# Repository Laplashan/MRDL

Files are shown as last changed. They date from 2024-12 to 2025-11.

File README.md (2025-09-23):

<header>

<!--
  <<< Author notes: Course header >>>
  Include a 1280×640 image, course title in sentence case, and a concise description in emphasis.
  In your repository settings: enable template repository, add your 1280×640 social image, auto delete head branches.
  Add your open source license, GitHub uses MIT license.
-->

# MRDL V0.2

_Tools, documentation and background of our datalogger._

</header>

<!--
  <<< Author notes: Step 1 >>>
  Choose 3-5 steps for your course.
  The first step is always the hardest, so pick something easy!
  Link to docs.github.com for further explanations.
  Encourage users to open new tabs for steps!
-->

## Introduction

_Welcome everyone_

MRDL was born from the necessity of getting a better undarstanding of the dynamics of our car. The motivation behind this repository is an exploration into the world of DIY electronics, the end goal being to create a functional prototype that can be permanently mounted on our MR23C.
The data logging system consists of 3 key aspects:

Firmware, this program is flashed onto the micro-controller so as to control its general operation and communicate with the server software.

Server software, this program exposes various API endpoints which handle hardware registration, configuration and telemetry.

Client software, this program is the source code for a web based interface for hardware reporting and configuration. (Currently using Blynk)

## Objective and needs (Constantly updating)

To get a better understanding of our car we need to be able to read data from various sectors, wich can include temperature, speed, position, acceleration, impacts, etc.
In this section, we´ll add a quick list mencioning the key spots to get data from, and what sensor/implement can be used to get that data as well as if its covered or not.

1. Speed | GPS sensor | Status: Completed. | Mounted anywhere on the car.
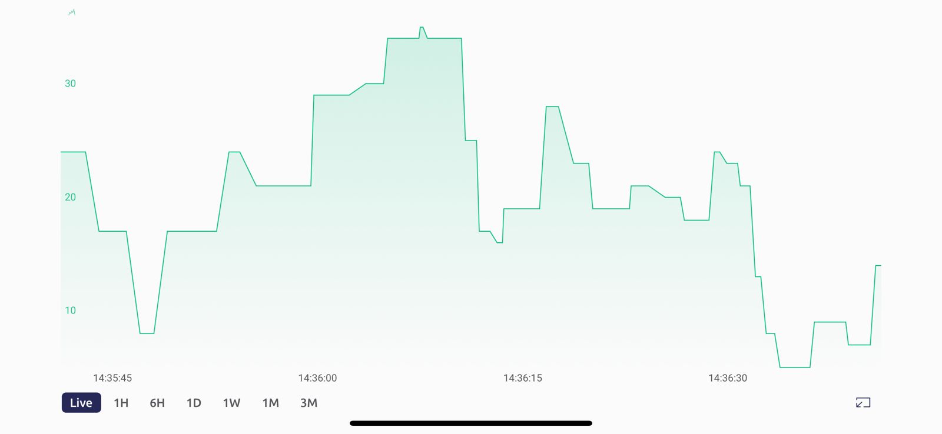
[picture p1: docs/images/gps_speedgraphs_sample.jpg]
speed
     
2. Position tracking | GPS sensor | Status: Partially completed (Issues w/ Blynk cloud) | Mounted anywhere on the car.
3. Engine RPM | Hall Effect | Status: 90% completed | Running in an Arduino board and sent thorugh Serial
4. Suspension shock dynamics | Unknown | Status: 0% | -
5. Reductor temp. | Thermocouple XS 168 or similar | Status: Partially completed, prog. completed, sensor unmounted | Bolted directly on the reductor.

Get help: [Post in our discussion board](https://github.com/orgs/skills/discussions/categories/introduction-to-github) &bull; [Review the GitHub status page](https://www.githubstatus.com/)

&copy; 2024 GitHub &bull; [Code of Conduct](https://www.contributor-covenant.org/version/2/1/code_of_conduct/code_of_conduct.md) &bull; [MIT License](https://gh.io/mit)

</footer>

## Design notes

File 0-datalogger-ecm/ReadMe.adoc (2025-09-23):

:Author: ernestrks
:Email:
:Date: 17/08/2025
:Revision: version#
:License: Public Domain

= Project: {Project}

Describe your project

== Step 1: Installation
Please describe the steps to install this project.

For example:

1. Open this file
2. Edit as you like
3. Release to the World!

== Step 2: Assemble the circuit

Assemble the circuit following the diagram layout.png attached to the sketch

== Step 3: Load the code

Upload the code contained in this sketch on to your board

=== Folder structure

....
 sketch123                => Arduino sketch folder
  ├── sketch123.ino       => main Arduino file
  ├── schematics.png      => (optional) an image of the required schematics
  ├── layout.png          => (optional) an image of the layout
  └── ReadMe.adoc         => this file
....

=== License
This project is released under a {License} License.

=== Contributing
To contribute to this project please contact: 

=== BOM
Add the bill of the materials you need for this project.

|===
| ID | Part name      | Part number | Quantity
| R1 | 10k Resistor   | 1234-abcd   | 10       
| L1 | Red LED        | 2345-asdf   | 5        
| A1 | Arduino Zero   | ABX00066    | 1        
|===

=== Help
This document is written in the _AsciiDoc_ format, a markup language to describe documents. 
If you need help you can search the http://www.methods.co.nz/asciidoc[AsciiDoc homepage]
or consult the http://powerman.name/doc/asciidoc[AsciiDoc cheatsheet]

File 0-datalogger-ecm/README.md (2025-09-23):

# Datalogger ECM
WEEMOS D1 Mini ESP3266
## Description
Captures and stores real-time data from other vehicle ECM and sensors for diagnostics and performance analysis.

## Folder Structure
- `src/` - Logging and data management code
- `tests/` - Test scripts for data integrity and performance
- `storage/` - Data formats and archival logic

## Dependencies
- ArduinoIoTCloud
- TinyGPSPlus

## Build Instructions
To build code for the ESP8266 using the Arduino IDE, follow these steps:

✅ 1. Install Arduino IDE
Download and install the latest version from arduino.cc.

✅ 2. Add ESP8266 Board Support
Open Arduino IDE.
Go to File > Preferences.
In the Additional Board Manager URLs, add:
http://arduino.esp8266.com/stable/package_esp8266com_index.json
Click OK.
✅ 3. Install ESP8266 Board Package
Go to Tools > Board > Boards Manager.
Search for ESP8266.
Click Install on the package by ESP8266 Community.
✅ 4. Select Your ESP8266 Board
Go to Tools > Board, and choose your specific board (e.g., NodeMCU 1.0, Wemos D1 Mini, etc.).

✅ 5. Connect Your Board
Plug in your ESP8266 via USB.
Select the correct Port under Tools > Port.
✅ 6. Write or Load Your Code

## Versioning
Current version: 0.0.0
Version history is tracked via Git tags: `datalogger-ecm-vX.Y.Z`

## Contact
Ernest
    github.com/Laplashan
    ernesto.ts06@gmail.com

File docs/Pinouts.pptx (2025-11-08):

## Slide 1

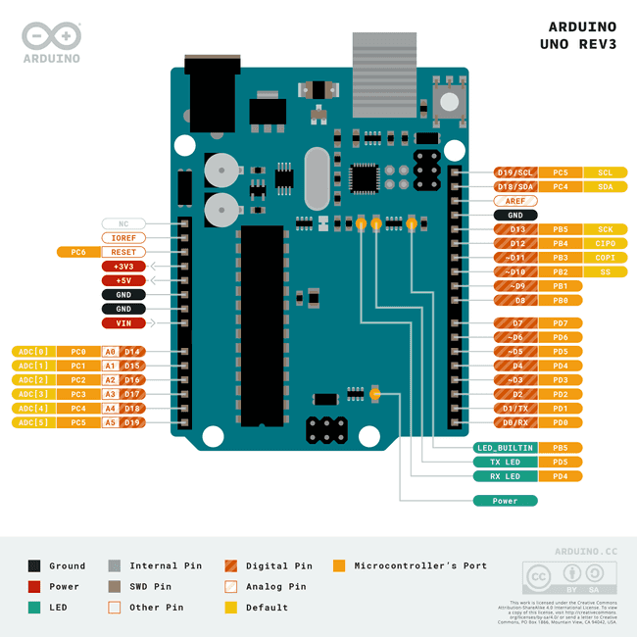
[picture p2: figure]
Arduino UNO Rev3 with Long Pins | Arduino Documentation
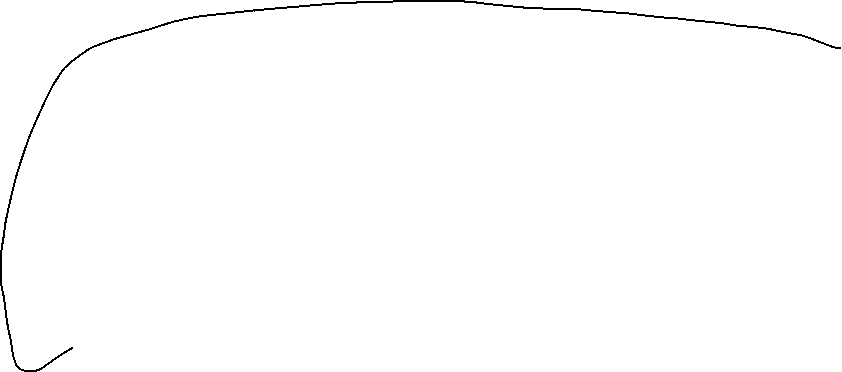
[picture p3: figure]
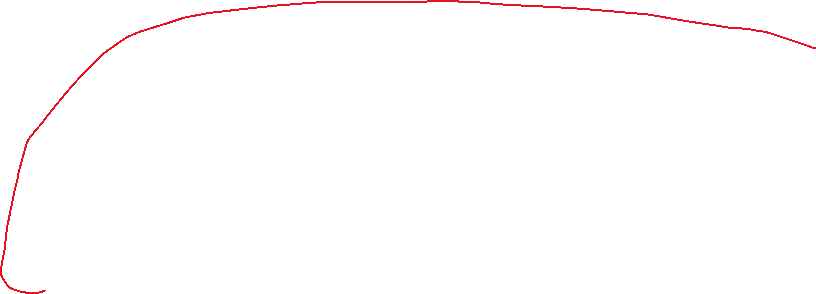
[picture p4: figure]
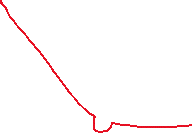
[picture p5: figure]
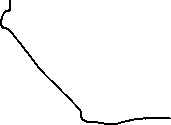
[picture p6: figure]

GND
Vin
Dout

GND
Vin
Dout

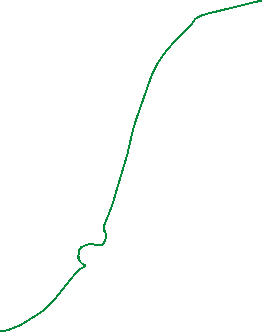
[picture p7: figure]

EngineHall Sensor

Gearbox Hall sensor

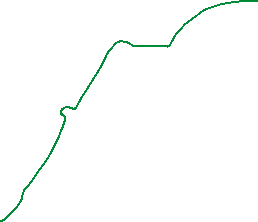
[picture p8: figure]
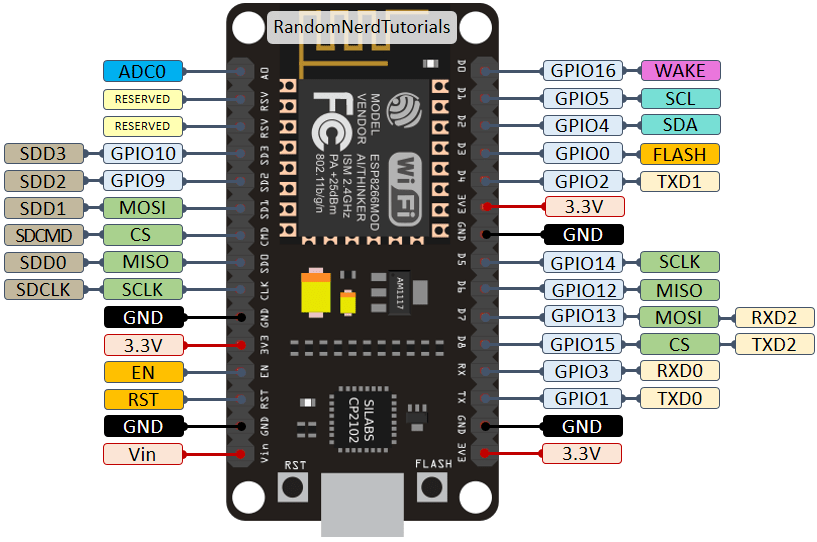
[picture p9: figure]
ESP8266 Pinout Reference: Which GPIO pins should you use? | Random Nerd Tutorials
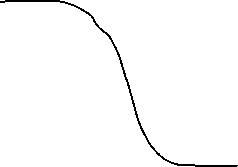
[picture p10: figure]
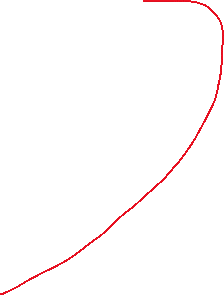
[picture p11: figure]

Tx - Rx

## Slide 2

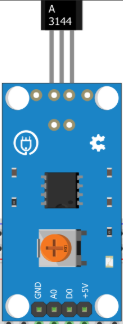
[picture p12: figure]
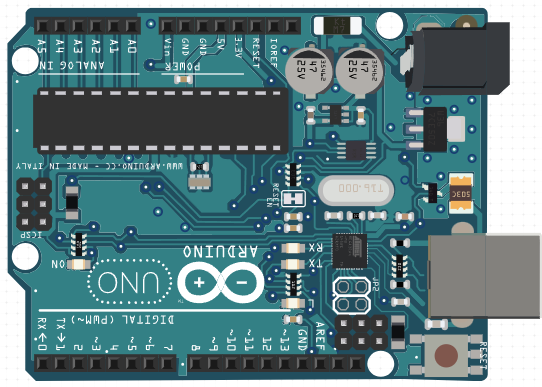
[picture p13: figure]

Gearbox

Engine

GND

5v+

GND

5v+

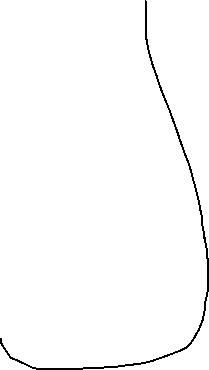
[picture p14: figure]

Arduino D2

Arduino D3

Serial: D8 -> ESP D5

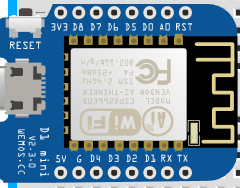
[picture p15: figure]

Conectar tierras

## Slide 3

Diagrama de GPS pendiente

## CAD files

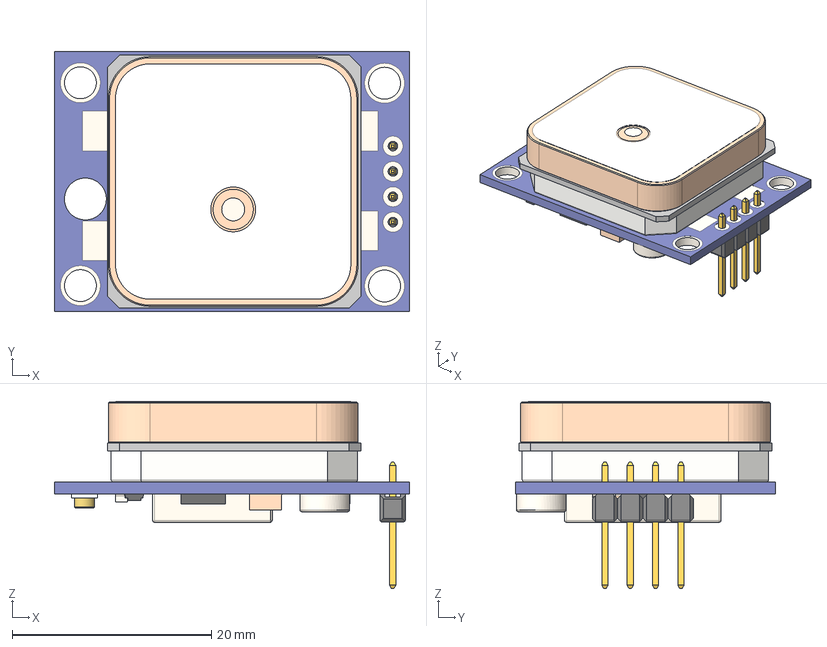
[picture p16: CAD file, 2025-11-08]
docs/CAD/v3 - gps/GY-NEO6MV2-withAnt v7.step
35.6 x 26.1 x 19.0 mm
Pin Header 1x4 TH Pitch 2.54mm

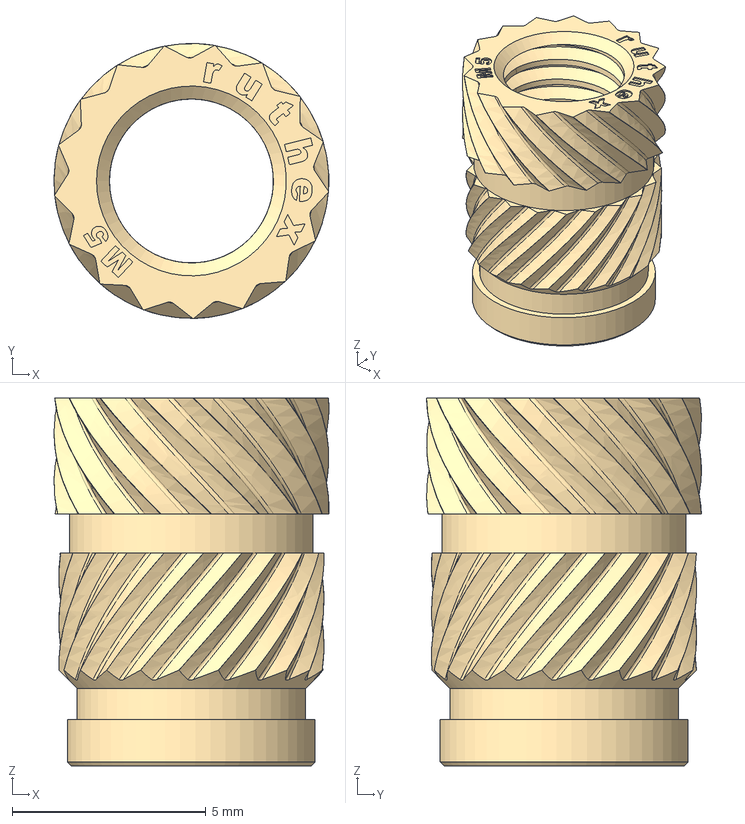
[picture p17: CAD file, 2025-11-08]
docs/CAD/v3 - gps/inserts/ruthex_RX-M5x9.5.step
7.10 x 7.10 x 9.50 mm

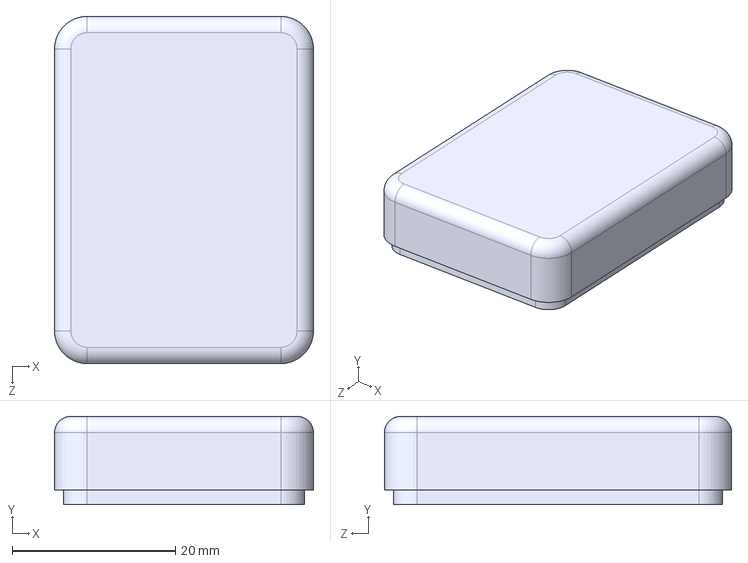
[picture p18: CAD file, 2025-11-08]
docs/CAD/v3 - gps/GPS_case_01-top.STEP
31.7 x 10.8 x 42.5 mm

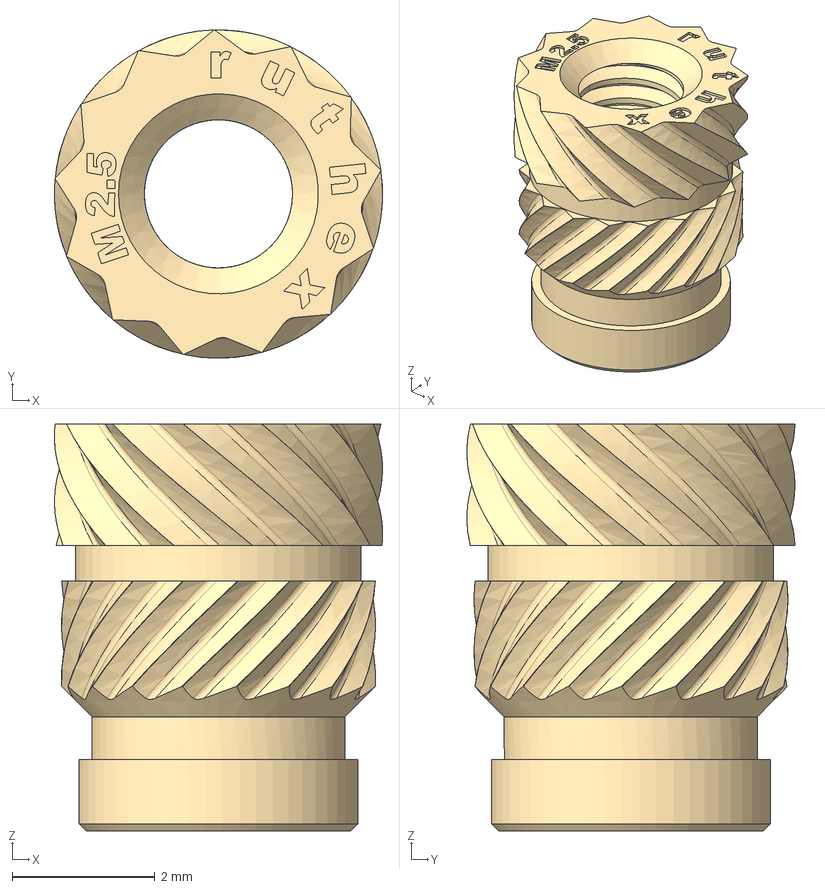
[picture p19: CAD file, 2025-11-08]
docs/CAD/v3 - gps/inserts/RX-M2.5x5.7.step
4.60 x 4.60 x 5.70 mm

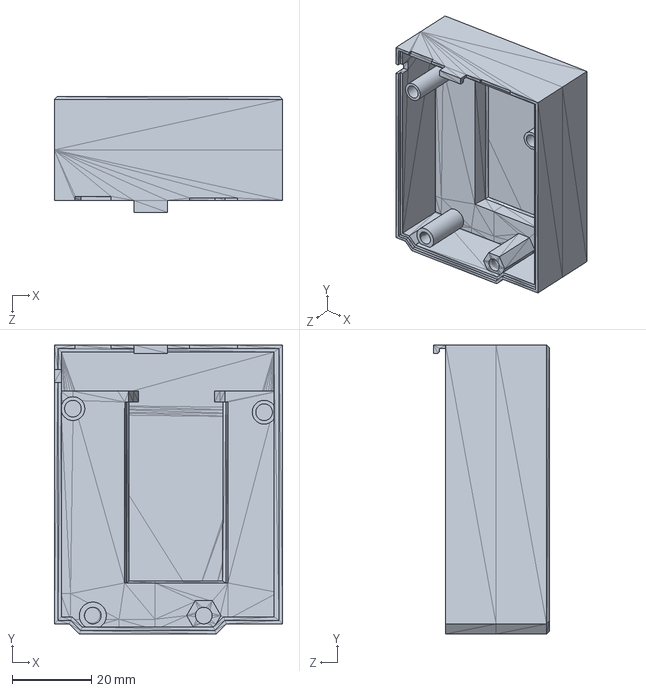
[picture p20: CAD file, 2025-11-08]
docs/CAD/v3 - gps/ECM_box_bottom.SLDPRT
57.5 x 72.8 x 29.1 mm

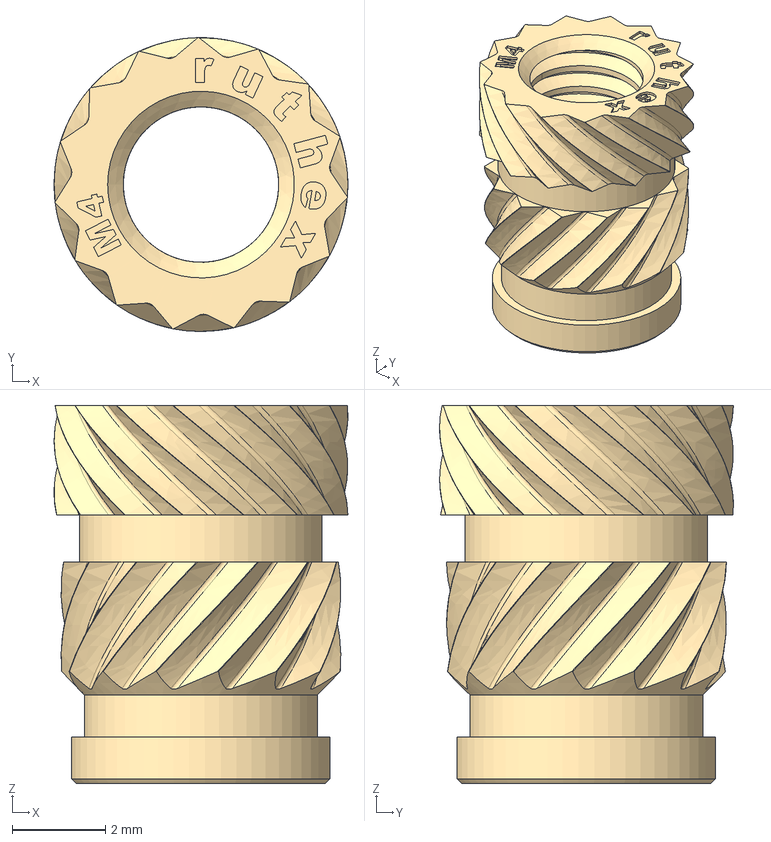
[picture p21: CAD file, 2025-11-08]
docs/CAD/v3 - gps/inserts/ruthex_RX-M4x8.1.step
6.30 x 6.30 x 8.10 mm

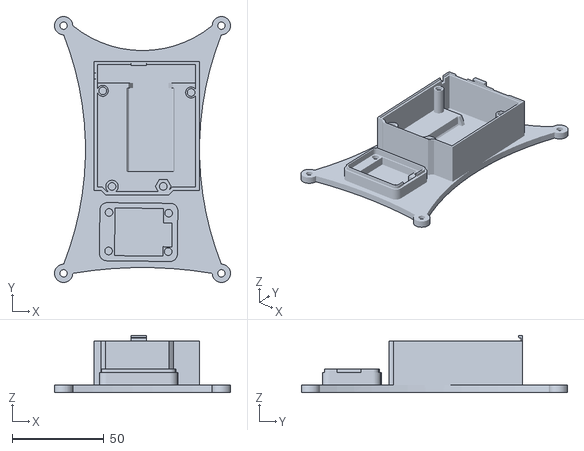
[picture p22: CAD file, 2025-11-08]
docs/CAD/v3 - gps/ECM Housing.STL
96.0 x 145.0 x 31.1

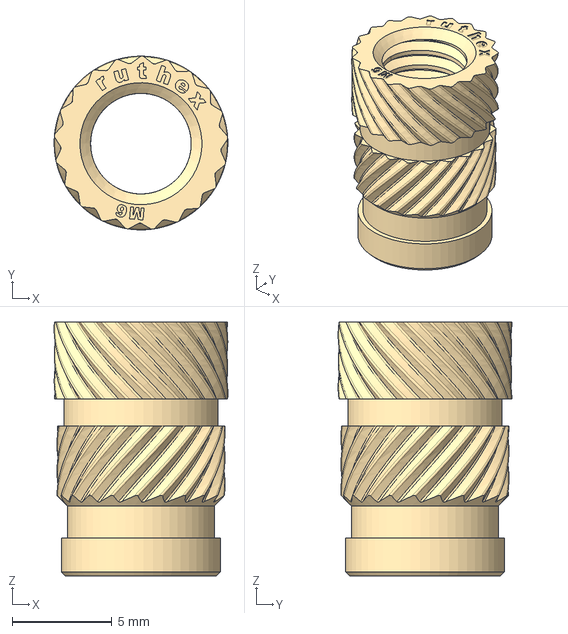
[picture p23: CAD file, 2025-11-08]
docs/CAD/v3 - gps/inserts/RX-M6x12.7.step
8.69 x 8.69 x 12.7 mm

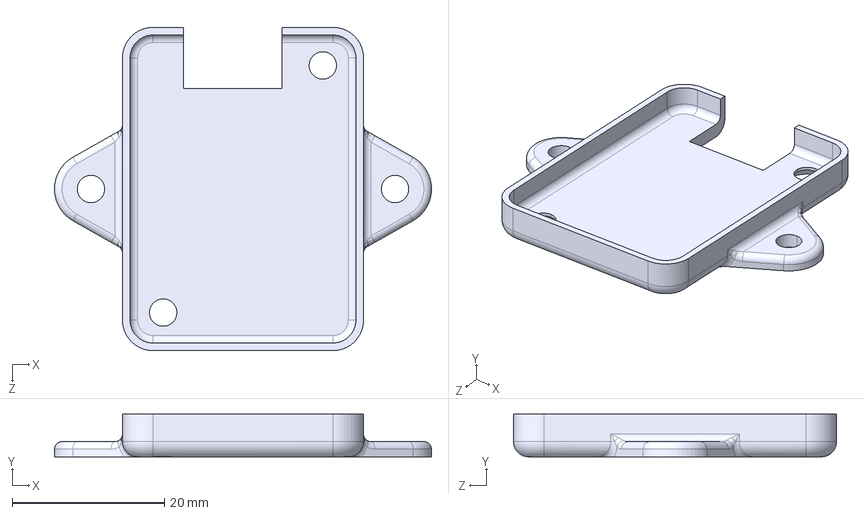
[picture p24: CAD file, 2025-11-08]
docs/CAD/v3 - gps/GPS_case_01-bottom_mounting_ears.STEP
49.6 x 5.60 x 42.5 mm

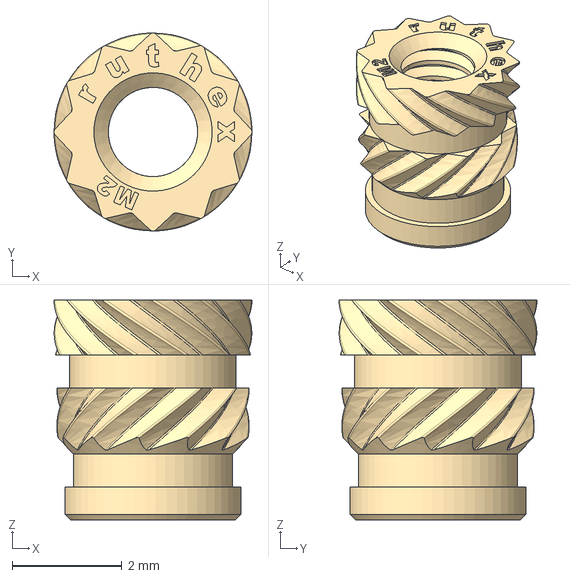
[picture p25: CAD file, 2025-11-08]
docs/CAD/v3 - gps/inserts/ruthex_RX-M2x4.step
3.60 x 3.60 x 4.00 mm

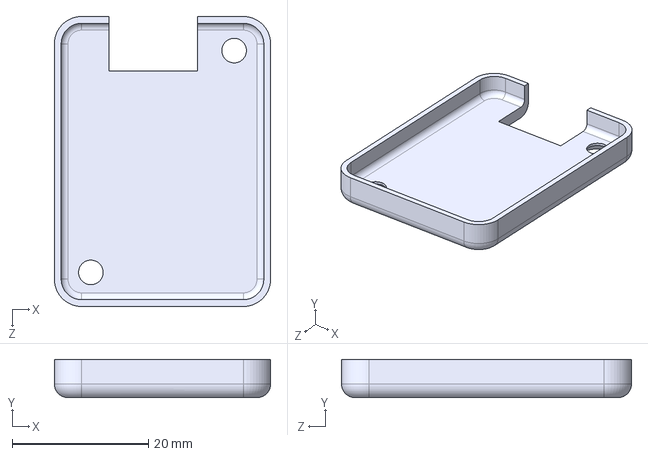
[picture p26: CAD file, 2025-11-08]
docs/CAD/v3 - gps/GPS_case_01-bottom.STEP
31.7 x 5.60 x 42.5 mm

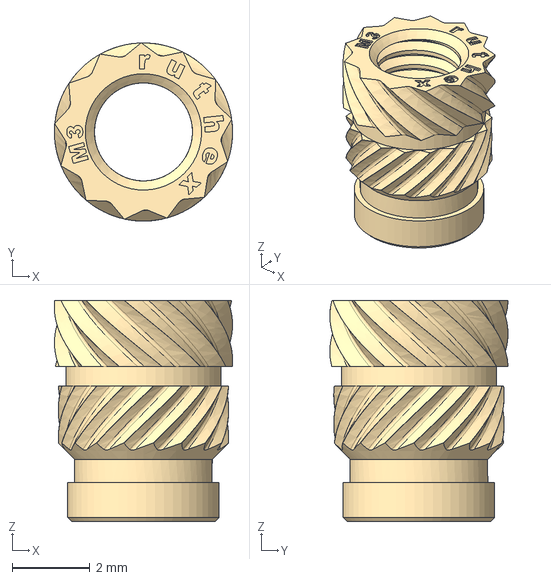
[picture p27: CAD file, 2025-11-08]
docs/CAD/v3 - gps/inserts/ruthex_RX-M3x5_7.stp
4.60 x 4.60 x 5.70 mm

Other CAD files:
docs/CAD/v3 - gps/ECM_box_bottom.STL
docs/CAD/v3 - gps/GPS_case_01-bottom_mounting_ears.STL
docs/CAD/v3 - gps/GPS_case_01-top.STL

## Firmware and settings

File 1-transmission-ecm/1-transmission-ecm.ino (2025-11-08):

#include <SoftwareSerial.h>
#include <TinyGPS++.h>

// =======================
// CONFIGURACIÓN DE PINES
// =======================

// GPS
#define GPS_RX 4       // GPS recibe datos del Arduino (TX)
#define GPS_TX 5       // GPS envía datos al Arduino (RX)
SoftwareSerial gpsSerial(GPS_TX, GPS_RX); // RX, TX invertidos para SoftwareSerial

// Comunicación serial adicional
SoftwareSerial mySerial(7, 8); // Pin 7 (RX), Pin 8 (TX)

// Sensores de RPM
#define MotorPin 2       // Pin D2: interrupción externa INT0
#define GearboxPin 3     // Pin D3: interrupción externa INT1

// =======================
// VARIABLES GLOBALES
// =======================

TinyGPSPlus gps;

const int pulse_per_rev = 8;
const int sample_time = 200;

int rpm_motor_count = 0;
int rpm_gearbox_count = 0;
int ten_ms_counter = 0;

float rpm_motor = 0;
float rpm_gearbox = 0;

bool ten_ms_counter_flag = false;
bool motor_sim = false;

// =======================
// CONFIGURACIÓN INICIAL
// =======================

void setup() {
  // Pines de simulación
  pinMode(9, OUTPUT);
  pinMode(10, OUTPUT);


  // Pines de entrada
  pinMode(MotorPin, INPUT);
  pinMode(GearboxPin, INPUT);

  // Inicializar comunicaciones
  Serial.begin(9600);       // USB
  mySerial.begin(9600);     // Comunicación por pin 8
  gpsSerial.begin(9600);    // GPS

  // Configurar Timer2
  SREG &= 0b01111111; // Deshabilitar interrupciones
  TIMSK2 |= 0b00000001; // Habilita la interrupción por desbordamiento
  TCCR2B = 0b00000011; // Preescala para que FT2 sea de 250 kHz
  SREG |= 0b10000000; // Habilitar interrupciones

  // Interrupciones externas
  attachInterrupt(digitalPinToInterrupt(MotorPin), rpm_motor_interrupt, RISING);
  attachInterrupt(digitalPinToInterrupt(GearboxPin), rpm_gearbox_interrupt, RISING);
}

// =======================
// BUCLE PRINCIPAL
// =======================

void loop() {
  // Leer datos del GPS
  while (gpsSerial.available() > 0) {
    gps.encode(gpsSerial.read());
  }

  // Si se cumplió el tiempo de muestreo
  if (ten_ms_counter_flag) {
    float lat = gps.location.isValid() ? gps.location.lat() : 0.0;
    float lng = gps.location.isValid() ? gps.location.lng() : 0.0;

    // Enviar por USB
    Serial.print(millis());
    Serial.print(",");
    Serial.print(rpm_motor);
    Serial.print(",");
    Serial.print(rpm_gearbox);
    Serial.print(",");
    Serial.print(lat, 6);
    Serial.print(",");
    Serial.println(lng, 6);

    // Enviar por pin 8
    mySerial.print(millis());
    mySerial.print(",");
    mySerial.print(rpm_motor);
    mySerial.print(",");
    mySerial.print(rpm_gearbox);
    mySerial.print(",");
    mySerial.print(lat, 6);
    mySerial.print(",");
    mySerial.println(lng, 6);

    ten_ms_counter_flag = false;
  }
}

// =======================
// INTERRUPCIONES DE RPM
// =======================

void rpm_motor_interrupt() {
  rpm_motor_count++;
}

void rpm_gearbox_interrupt() {
  rpm_gearbox_count++;
}

// =======================
// INTERRUPCIÓN DEL TIMER
// =======================

ISR(TIMER2_OVF_vect) {
  motor_sim = !motor_sim;
  digitalWrite(9, motor_sim);
  digitalWrite(10, motor_sim);

  ten_ms_counter++;
  if (ten_ms_counter > 195) {
    rpm_motor = (float(rpm_motor_count) / pulse_per_rev) * (1000.0 / sample_time) * 60.0;
    rpm_gearbox = (float(rpm_gearbox_count) / pulse_per_rev) * (1000.0 / sample_time) * 60.0;

    rpm_motor_count = 0;
    rpm_gearbox_count = 0;
    ten_ms_counter_flag = true;
    ten_ms_counter = 0;
  }
}

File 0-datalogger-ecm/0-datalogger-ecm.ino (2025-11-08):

#include "arduino_secrets.h"
#include "thingProperties.h"
#include <SoftwareSerial.h>

// Comunicación serial con Arduino Uno
SoftwareSerial swSer(D5, D4); // D5 = RX, D4 = TX

String incomingData = "";
float elapsed;

void setup() {
  Serial.begin(9600);
  swSer.begin(9600);

  WiFi_Start();
  initProperties();
  ArduinoCloud.begin(ArduinoIoTPreferredConnection);

  setDebugMessageLevel(2);
  ArduinoCloud.printDebugInfo();
}

void WiFi_Start() {
  WiFi.begin(SSID, PASS);
  Serial.print("Connecting to WiFi");
  while (WiFi.status() != WL_CONNECTED) {
    delay(1000);
    Serial.print(".");
  }
  Serial.println("\nConnected!");
  Serial.println("IP address: ");
  Serial.println(WiFi.localIP());
}

void loop() {
  ArduinoCloud.update();

  while (swSer.available()) {
    char c = swSer.read();
    if (c == '\n') {
      parseData(incomingData);
      incomingData = "";
    } else {
      incomingData += c;
    }
  }
}

void parseData(String data) {
  // Separar por comas
  int p1 = data.indexOf(',');
  int p2 = data.indexOf(',', p1 + 1);
  int p3 = data.indexOf(',', p2 + 1);
  int p4 = data.indexOf(',', p3 + 1);

  if (p1 > 0 && p2 > p1 && p3 > p2 && p4 > p3) {
    String timeStr = data.substring(0, p1);
    String rpmEngStr = data.substring(p1 + 1, p2);
    String rpmGbxStr = data.substring(p2 + 1, p3);
    String latStr = data.substring(p3 + 1, p4);
    String lngStr = data.substring(p4 + 1);

    // Convertir a valores
    elapsed = timeStr.toFloat();
    rpm_eng = rpmEngStr.toFloat();
    rpm_gbx = rpmGbxStr.toFloat();
    latitude = latStr.toFloat();
    longitude = lngStr.toFloat();

    
    gpsLocation = {latStr.toFloat(), lngStr.toFloat()}; // Actualiza el mapa


    // Mostrar en consola
    Serial.print("Tiempo: "); Serial.print(elapsed);
    Serial.print(" ms, RPM Motor: "); Serial.print(rpm_eng);
    Serial.print(", RPM Gearbox: "); Serial.print(rpm_gbx);
    Serial.print(", Lat: "); Serial.print(latitude);
    Serial.print(", Lng: "); Serial.println(longitude);
  }
}

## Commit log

2025-08-28 Aug_20_test_files
    Ernest and I putted together files for initial test on car. Several issues detected like:
    -Bad cloud connectivity
    -Unstable sampling rate in cloud data
    -RPM values doubled when connected to USB
    -Unstable GPS Meassurements if done in datalogger
    [0-datalogger-ecm.ino, 1-transmission-ecm.ino]
2025-09-18 Included Gearbox RPM feature
    Into the same transmission ecm. Outputs gearbox rpm from PIN 3 into serial.
    Outputs: TIME, Engine_RPM, Gearbox_RPM
2025-09-18 Created new thing a device for building
    Also fixed datalogger-ecm conection issues
    [0-datalogger-ecm.ino]
2025-09-18 Updated pinout doc with gearbox
2025-11-08 Implementacion de GPS a traves de Arduino
    -El GPS envia al datos a arduino que son luego enviados al esp86
    -Cambio implimentados en cloud
2025-11-08 Inclución de CAD de esta implementación
    [ECM Housing.STL, ECM_box_bottom.SLDPRT, ECM_box_bottom.STL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]
